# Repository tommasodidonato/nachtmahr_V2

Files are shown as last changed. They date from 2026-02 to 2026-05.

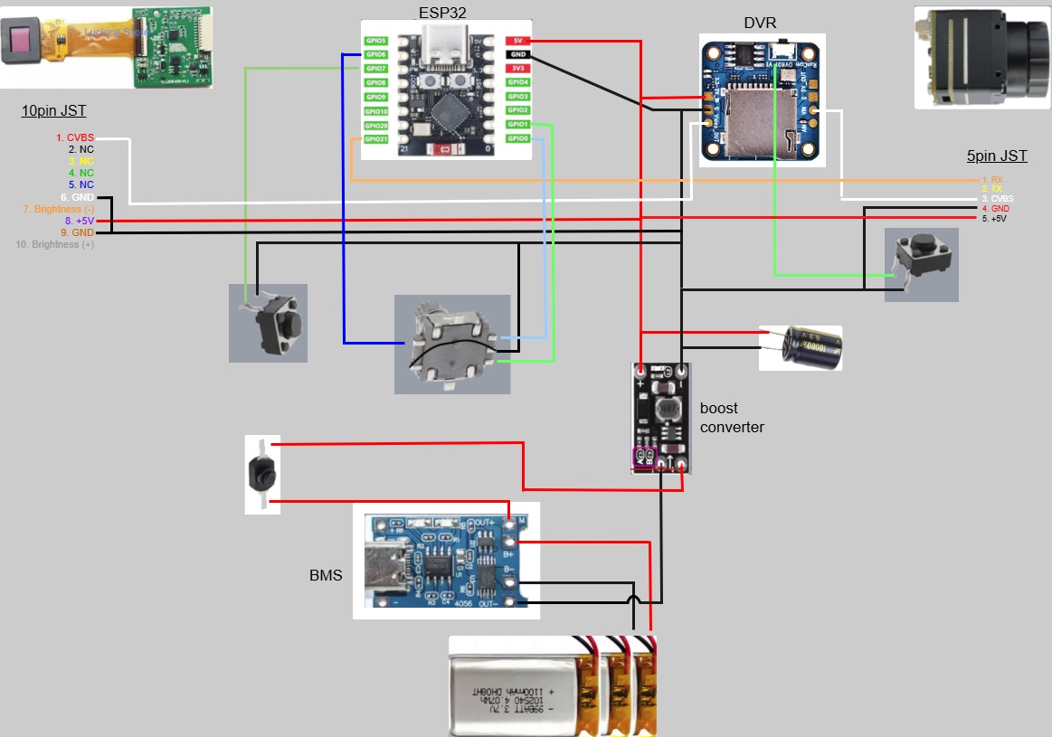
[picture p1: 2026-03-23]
wiring nachtmahr 2.jpg

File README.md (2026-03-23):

# PVS Nachtmahr V2
A thermal monocular, based on the original Idea of Lupus Worax, that use N6 thermal core

The idea here is to have a modified version of the Nachtmahr (https://www.printables.com/model/1259454-pvs-nachtmahr-50hz-thermal-vision-light-weight-dvr) , that will work with an N6 thermal core, and use the same "new" control hardware: rotary encoders and push buttons.
Why to use this, instead of the Gremlin V2? 
Well.. first of all, because it has more space... 😉
Second, it can use a DVR (sometimes very very handy). Last but not least, I really loved the idea of an internal rechargeable battery.

This is a WIP, completely based on the great work of Lupus Worax. Many guides can be found on his discord channel (https://discord.com/channels/1336624444369670154)

### ESP Firmware
The last firmware to use can be found here: https://discord.com/channels/1336624444369670154/1337755087228895282 
| Action | Single Click / Rotation | Shift Held (Thumb Button - GPIO 7) |
| :--- | :--- | :--- |
| **Rotate Encoder** | **Digital Zoom** (1x to 8x) | **Brightness** (0-127) |
| **Short Press (Encoder)** | **Cycle Palettes** (5 modes) | **Cycle Contrast** (Incremental) |
| **Long Press (Encoder)** | **Image Enhancement** (1.5s) | **Dead Pixel Correction** (5s) |
| **Short Press (Thumb)** | **Manual Calibration** (NUC) | — |
| **Long Press (Thumb)** | **Toggle Auto-Calibration** (3s) | **Toggle WiFi/OTA** (5s) |

### Build guide
Building the Nachtmahr v2 is very similar to V1, and you can find the guide [here](https://docs.google.com/document/d/1FID4HvsZnoMsb9pfEZISi7Dp_-eUuumutZ-1HBHcEDI/edit?usp=drive_link). The main difference is related to the 2 push buttons (the one for DVR and the one on the main body). You have to cut out 2 of the 4 pins (check with a multimeter which one to keep), and file the button so it can fit perfectly in the home. Sold the 2 wires before inserting it, and then you're good to go.
The complete wiring schematics can be found [here](https://github.com/tommasodidonato/nachtmahr_V2/blob/main/wiring%20nachtmahr%202.jpg)

### Printing tips
You can use whatever material you like best. PLA is ok, as long as you don't plan to leave it in the car during the hot season. The images you see here refer to my build in ASA. I strongly suggest 4 walls, infill at least 15%, line height 0.2 is ok. For TPU, I printed with 0.16 line height. 
Supports are mandatory for many parts, settings depend on your printer (I used tree structure, 0.4 distance from x/y, density 70%). If you plan to use ASA or other shrinking materials, print accordingly; I strongly suggest to do a dimensional test print before printing everything. I also enlarged the screw holes with a drill before the assembly (it will saves you a lot of heachaches)

### General tips
Charge your LiPo batteries separately before assembling the power block. 
**Remember to remove the A and B resistance** from the boost converter. Before going on, double check with a multimeter that the booster output is really 5V... 
When glueing the power button and the rotary encoder, do not use normal super glue (if it goes into the button, then you will have to change it!). I suggest the gel one.

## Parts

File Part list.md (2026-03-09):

This file is still WIP, it is the list of the things to be purchased to build the Nachtmahr V2 

## BOM
### N6 Series Thermal core:
https://www.alibaba.com/product-detail/subject_1601691636517.html

### Buffer Capacitor: 6.3V10000UF 2PCS
https://it.aliexpress.com/item/1005005232537739.html

### NP18 18x Lens:  The WHOLE lens and NOT just the core!! 
https://it.aliexpress.com/item/1005008394658301.html

### Voltage booster: REMOVE A, B contact to set it to 5 volts!
https://it.aliexpress.com/item/1005004910145161.html

### Main Power switch: 
https://it.aliexpress.com/item/1005001453441011.html

### Rotary Encoder:
https://it.aliexpress.com/item/1005001637061380.html

### Push buttons 6x6x4.3mm
https://it.aliexpress.com/item/1005002550688671.html

### 0,39" Display: choose the option with colors!
https://it.aliexpress.com/item/1005007905243096.html

### ESP32 
https://de.aliexpress.com/item/1005008212278653.html

### JST  connector for camera control with micro controller:
Amazon: 5PIN 1.25mm
https://www.amazon.de/vuniversum-1-25mm-Female-Stecker-Kupplung/dp/B0BNF6J1RJ
or on aliexpress:
https://de.aliexpress.com/item/1005002332868366.html 10 pairs 5P 

### Brass heat melt inserts: M3 ( 100 pieces) 
https://it.aliexpress.com/item/1005005789416899.html

### Grub screws for focus ring: M2,5 5mm
https://it.aliexpress.com/item/1005007404470826.html

### Main case screws: M3 16mm (20 pcs)
https://it.aliexpress.com/item/1005008082257314.html

### Front tube screws: M3 25mm 
https://it.aliexpress.com/item/1005006427396773.html

### Camera screw inserts: 
https://it.aliexpress.com/item/1005005468090661.html

### USB C Charging board: 
https://it.aliexpress.com/item/4001046570639.html

### RunCam DVR Micro SD Recorder addon (optional): 
https://it.aliexpress.com/item/1005008678943146.html

### Lipo 3,7 V 102540 1100 mAh (2! I suggest to buy 3, some found to be defected)
https://it.aliexpress.com/item/1005006278332065.html

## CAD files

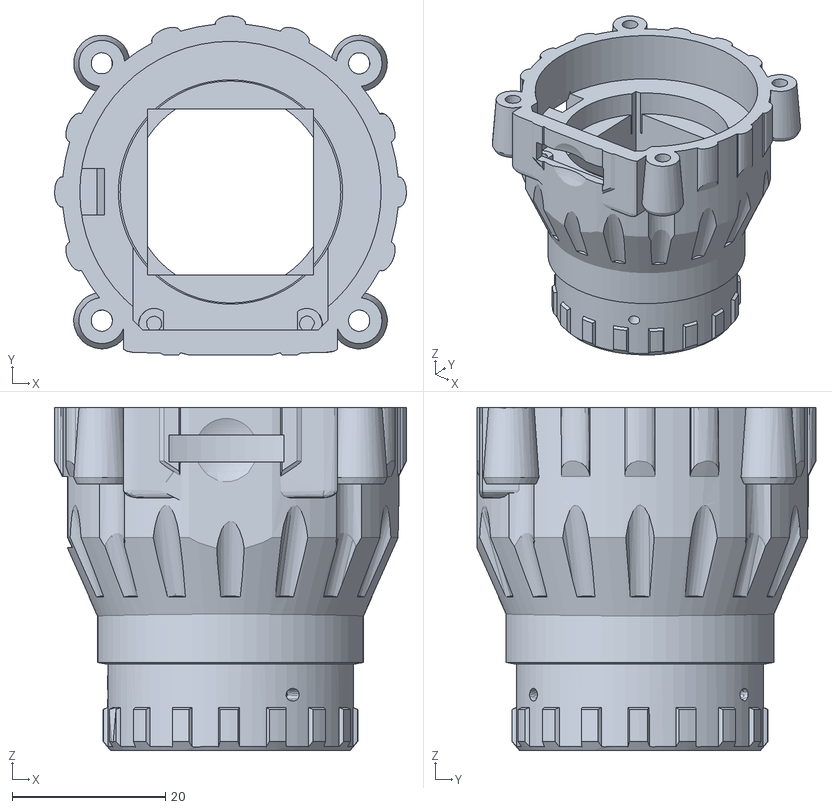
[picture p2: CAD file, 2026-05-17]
STL/Front camera housing with DVR.stl
46.0 x 44.3 x 44.8

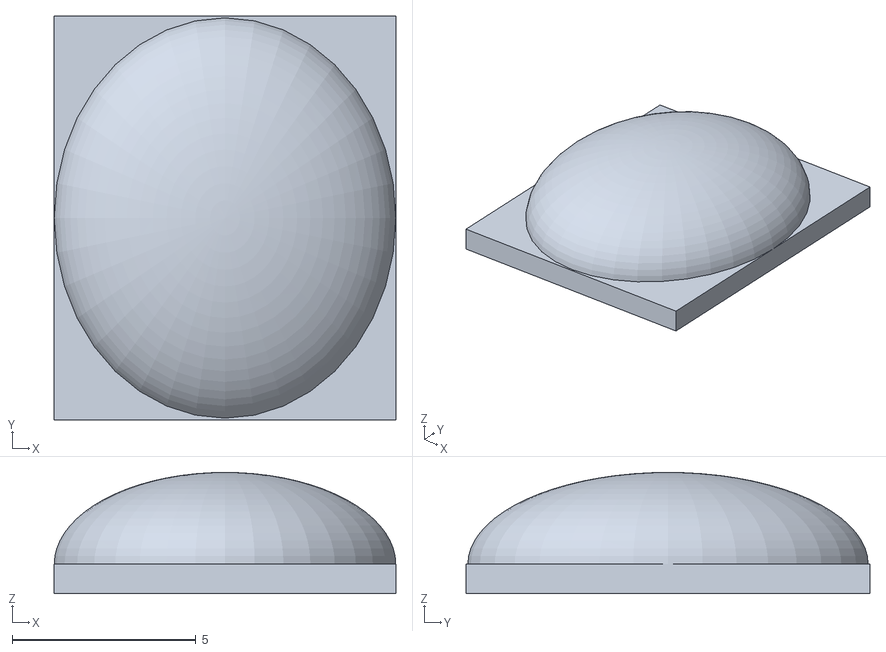
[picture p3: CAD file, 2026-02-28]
STL/TPU DVR button.stl
9.30 x 11.0 x 3.30

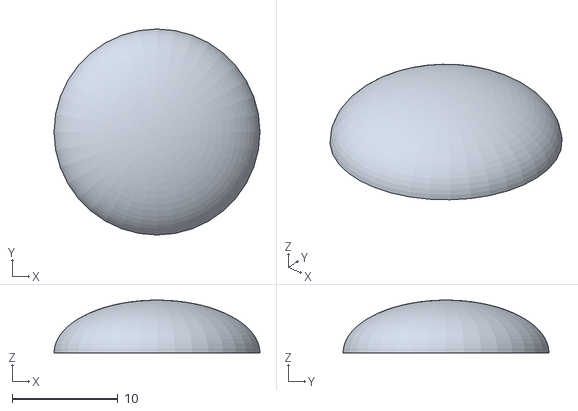
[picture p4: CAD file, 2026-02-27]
STL/TPU button cover.stl
19.5 x 19.5 x 5.00

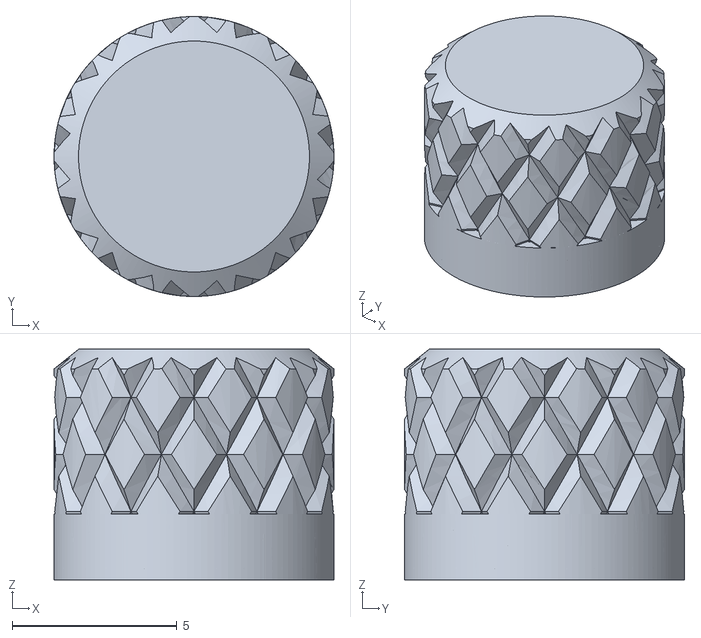
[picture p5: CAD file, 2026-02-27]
STL/Rotary cover.stl
8.50 x 8.50 x 7.00

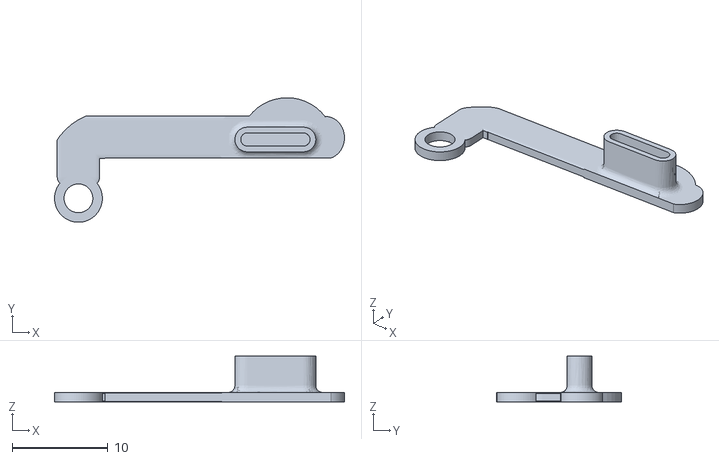
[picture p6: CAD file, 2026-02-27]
STL/TPU USB dust cover.stl
30.3 x 13.0 x 4.80

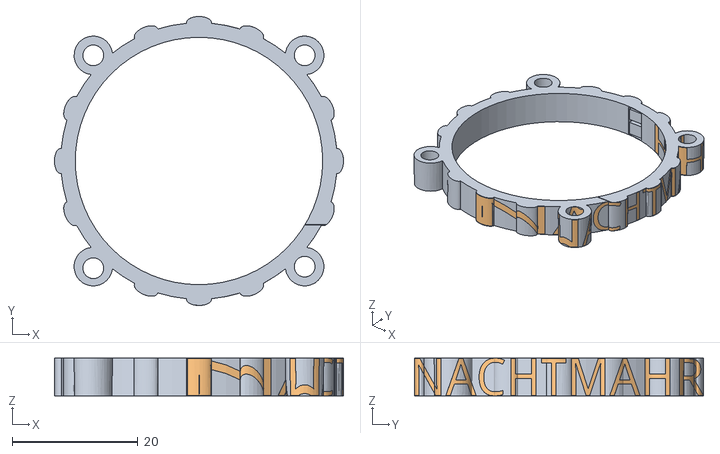
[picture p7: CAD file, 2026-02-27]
STL/Tube spacer.obj
46.0 x 46.0 x 6.00

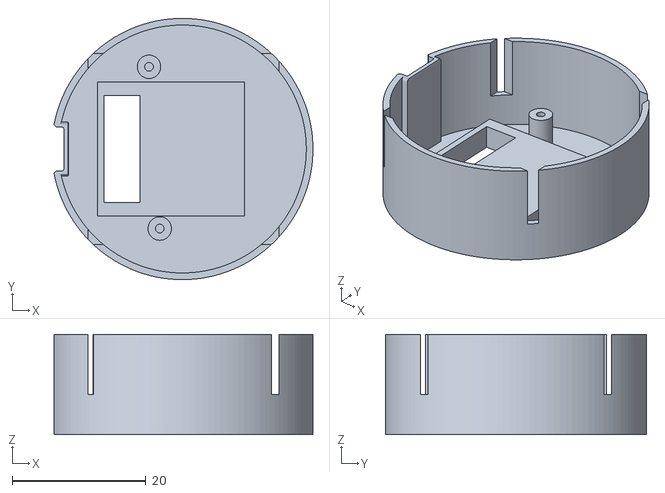
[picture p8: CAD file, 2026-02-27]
STL/Display frame.stl
38.7 x 39.0 x 15.0

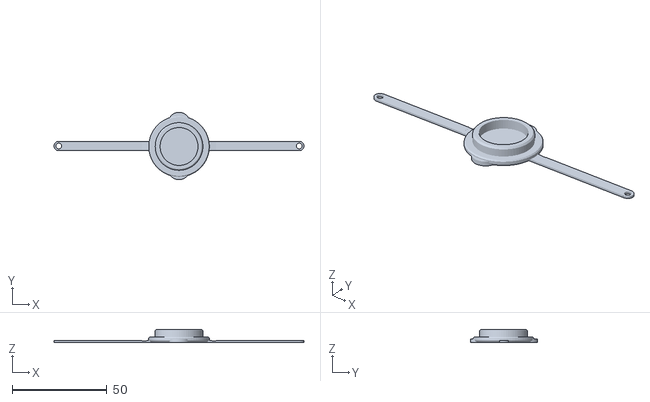
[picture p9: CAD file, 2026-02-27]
STL/TPU lens cap.stl
132.0 x 35.5 x 7.00

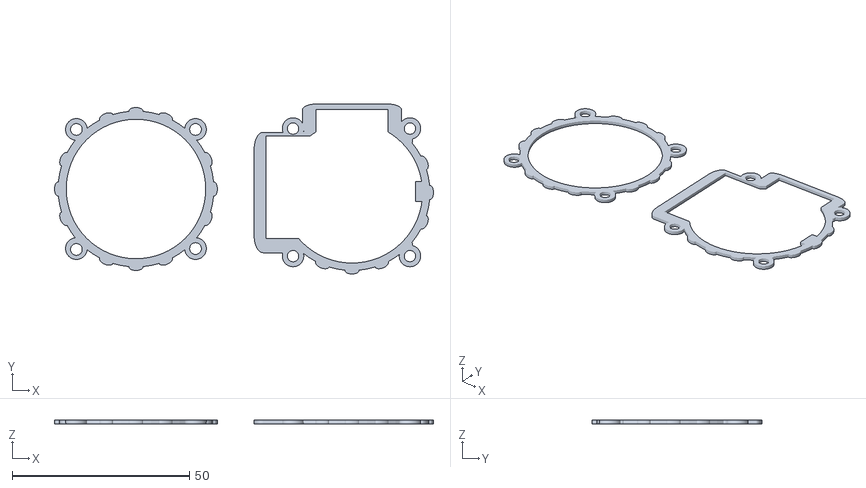
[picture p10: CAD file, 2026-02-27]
STL/TPU sealings.stl
107.0 x 48.0 x 1.01

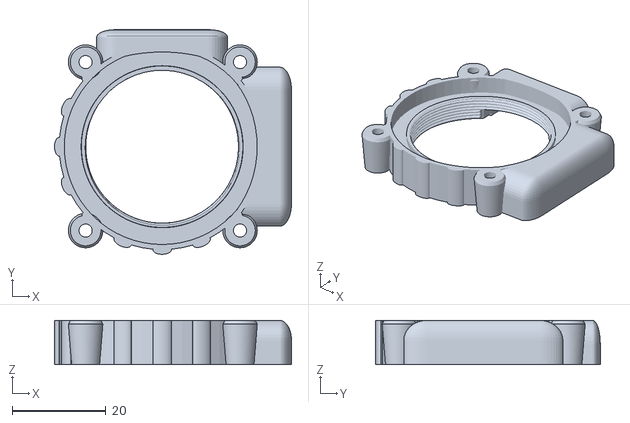
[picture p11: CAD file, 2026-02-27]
STL/Lens holder.stl
50.6 x 48.0 x 9.43

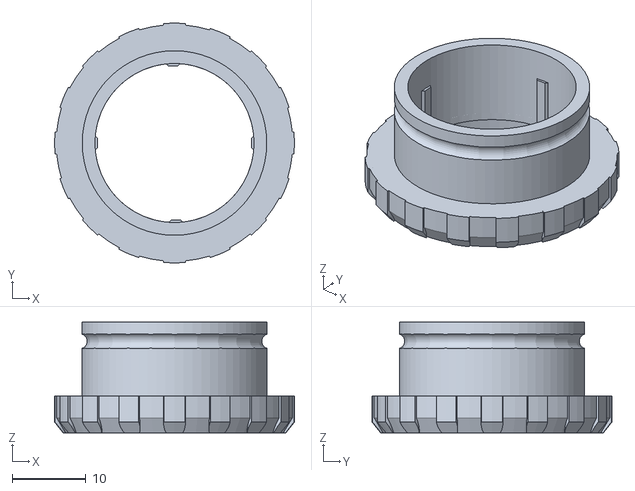
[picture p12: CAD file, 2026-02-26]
STL/Focus ring.stl
32.5 x 32.5 x 15.0

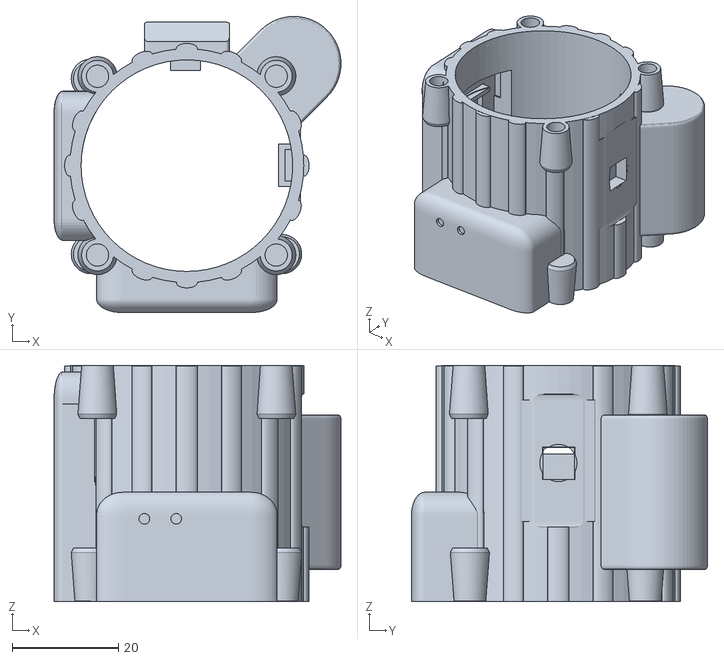
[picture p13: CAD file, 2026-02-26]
STL/Middle tube.stl
54.0 x 55.7 x 44.4

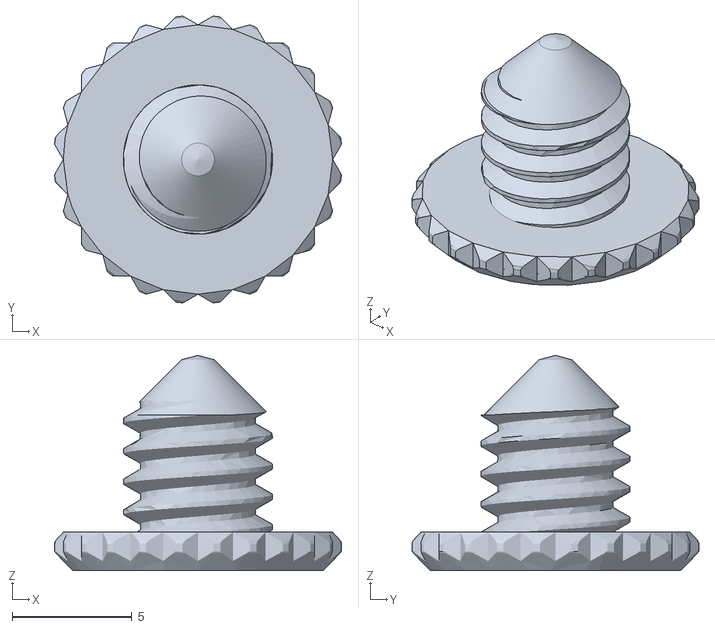
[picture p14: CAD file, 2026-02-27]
STL/TPU screw.stl
12.0 x 12.0 x 9.00

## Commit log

2026-02-26 Create STL part list
    List of all STL files to be printed
2026-02-27 Update STL part list
    Added tips for printing
2026-02-27 Add files via upload
    Added more STL files
    [Display frame.stl, Lens holder.stl, TPU USB dust cover.stl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]
2026-02-27 Rename STL part list to STL/STL part list
2026-02-27 Rename Display frame.stl to STL/Display frame.stl
    [Display frame.stl]
2026-02-27 Rename Focus ring.stl to STL/Focus ring.stl
    [Focus ring.stl]
2026-02-27 Rename Lens holder.stl to STL/Lens holder.stl
    [Lens holder.stl]
2026-02-27 Rename Middle tube.stl to STL/Middle tube.stl
    [Middle tube.stl]
2026-02-27 Rename Tube spacer.obj to STL/Tube spacer.obj
    [Tube spacer.obj]
2026-02-27 Rename TPU sealings.stl to STL/TPU sealings.stl
    [TPU sealings.stl]
2026-02-27 Rename TPU screw.stl to STL/TPU screw.stl
    [TPU screw.stl]
2026-02-27 Rename TPU lens cap.stl to STL/TPU lens cap.stl
    [TPU lens cap.stl]
2026-02-27 Rename TPU USB dust cover.stl to STL/TPU USB dust cover.stl
    [TPU USB dust cover.stl]
2026-03-23 Update README.md
    Added a link to the wiring schema
2026-05-17 Add files via upload
    missing file
    [Front camera housing with DVR.stl]
